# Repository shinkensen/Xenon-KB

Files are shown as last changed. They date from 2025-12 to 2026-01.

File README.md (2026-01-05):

# Xenon-KB

The Xenon KB is an 85%, fully rgb backlit (96 zone), fully wireless keyboard powered by an esp32 chip with a unique key design. 

<br/>
<br/>
More specifications:
<br/>
- CPG151101D01 Switches (From HanElectricty) https://www.lcsc.com/product-detail/C49234238.html
<br/>
- Backlit by an array of SK6812MINI-E's
<br/>
- 5000mah LiPo 1s 3.7v battery
<br/>
- Fully Custom Keycaps & Case
  <br/>
- Wireless with BLE from the onboard ESP-32
  <br/> 
- Rotary Encoder
<br/>
BOM:
https://docs.google.com/spreadsheets/d/1MoRKEyVhLm31BRy2YZbWCOqMzg5SxBg5gL_tJ-3HmaI/edit?usp=sharing
<br/>




<br/>
BOM for parts
https://drive.google.com/file/d/10kQmmBENU_pZNQ-ZYw2EzStenI3IcliA/view?usp=drive_link
<br/>

<br/>

Google Drive Folder: https://drive.google.com/drive/folders/1_GYV8TD-opU9jGdwIyMG7L0oK-KXUA7e?usp=sharing

<br/>
<br/>
Why I built this: Wanted a fully backlit keyboard for coding in the night. Also wanted a mechanical keyboard.
<br/>
<br/>

Images:



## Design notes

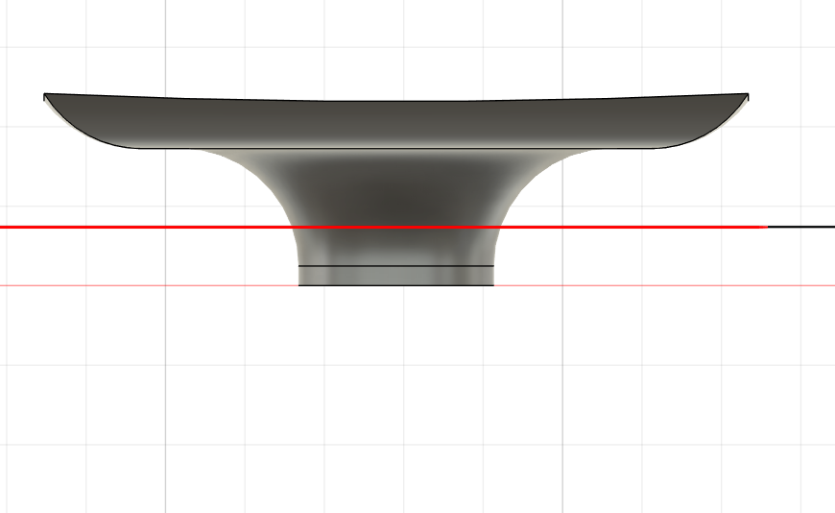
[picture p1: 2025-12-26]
CAD/Keycap.png

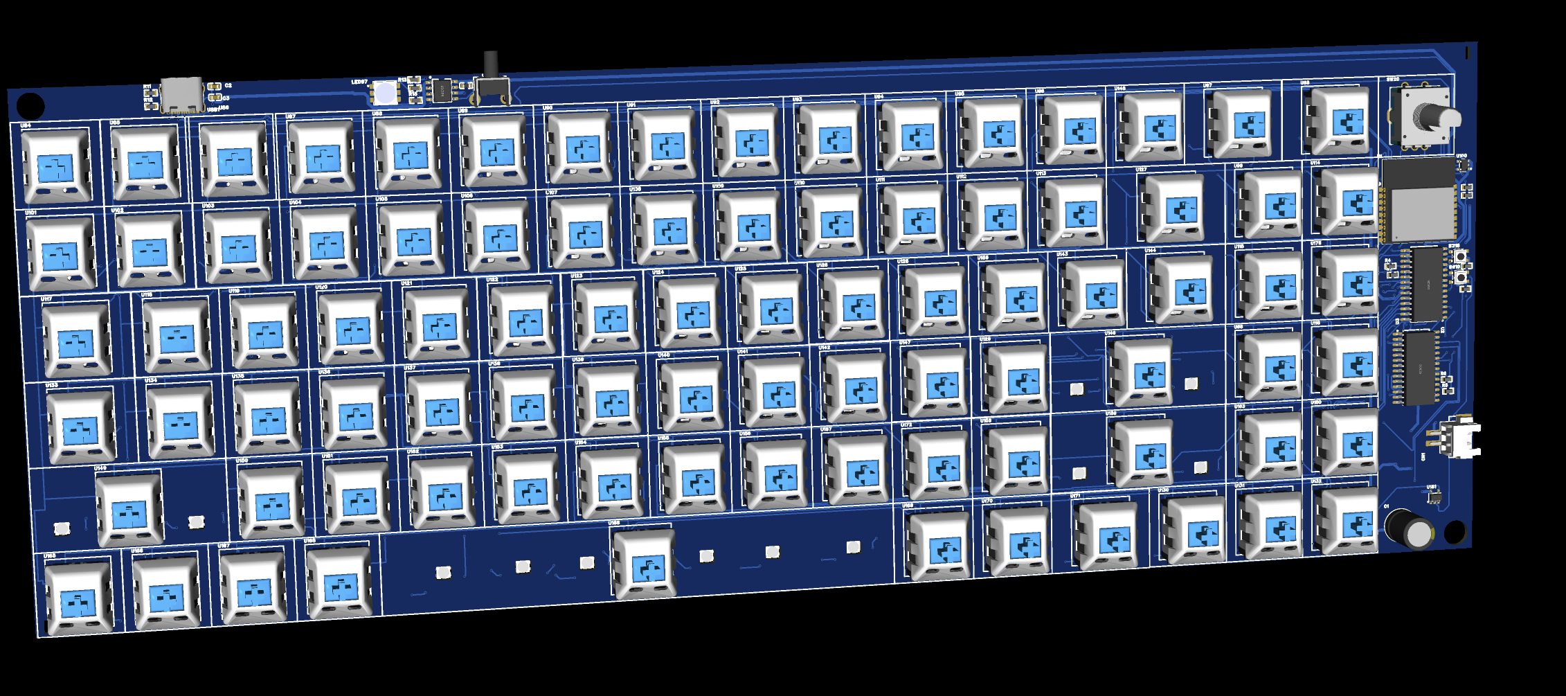
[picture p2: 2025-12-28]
pcb/PCB (Image 2).png

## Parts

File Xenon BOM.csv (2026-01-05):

Name | Cost | With Tax | Links | Links (Additional) | Column 6 | Column 1 | Column 2 | Column 3 | Column 4 | Column 5 | Column 7 | Column 8 | Column 9 | Column 10 | Column 11 | Column 12 | Column 13 | Column 14 | Column 15 | Column 16 | Column 17 | Column 18 | Column 19 | Column 20 | Column 21 | Column 22 | Column 23 | Column 25 | Column 27
PCB | $ 37.50 |  | https://drive.google.com/file/d/1959B7aU0yXcRoiEhPKL7f8_TZMNGbxId/view |  |  | LCSC# | Mfr. | Mrf# | Description | Package | Value | Customer Part Number | Quantity | Target Price(USD) | Target Lead Time(Business Days) | Mrf# | Mfr. | Order Qty. | Unit Price(USD) | Ext.Price(USD) | LCSC# | Package | Min | Mult | SPQ | Availability | Stock Status | Description | Product Link
Parts | $ 43.19 |  | https://drive.google.com/file/d/1eT5wwbHMu8irWbdyzTQDoIp_ezeuC_NU/view | https://drive.google.com/file/d/10kQmmBENU_pZNQ-ZYw2EzStenI3IcliA/view?usp=drive_link | <- BOM for parts -> | C49234238 | HanElectricity(瀚源) | CPG151101D01 | Switches | SW-TH_CPG151101D9X |  | - | 88 |  |  | CPG151101D01 | HanElectricity | 90 | 0.0809 | 7.28 | C49234238 | Through Hole | 5 | 5 | 500 | 4065 | In Stock | 60gf Black Switch Through Hole Pushbutton Switches RoHS | https://www.lcsc.com/product-detail/C49234238.html
battery | $14.24 |  | https://www.amazon.com/gp/product/B0D7LVP6RD/ref=ox_sc_act_title_1?smid=A1NOQTMMT39TJ0 |  |  | C2907044 | FOJAN(富捷) | FRC0603F5101TS | Ressistor | R0603 |  | - | 2 |  |  | FRC0603F5101TS | FOJAN | 100 | 0.0009 | 0.09 | C2907044 | 603 | 100 | 100 | 5000 | 4839000 | In Stock | 5.1kΩ ±1% 100mW 0603 Thick Film Resistor | https://www.lcsc.com/product-detail/C2907044.html
Case and Keycaps (Shipping) | $ 6.38 |  | https://drive.google.com/file/d/1fY9vsn8Mw1SYbBaPE8fCq7_2en8WSZ7o/view |  |  | C | SHOU HAN(首韩) | TYPE-C 16PIN 2MD(073) | USB-C | USB-C-SMD_TYPE-C-6PIN-2MD-073 |  | - | 1 |  |  | TYPE-C 16PIN 2MD(073) | SHOU HAN | 20 | 0.0631 | 1.26 | C2765186 | SMD | 20 | 20 | 1000 | 366060 | In Stock | USB-C (USB TYPE-C) Receptacle Connector 16 Position Surface Mount, Right Angle | https://www.lcsc.com/product-detail/C2765186.html
 |  |  |  |  |  | C1591 | SAMSUNG(三星) | CL10B104KB8NNNC | Capacitor | C0603 |  | - | 2 |  |  | CL10B104KB8NNNC | Samsung Electro-Mechanics | 100 | 0.0026 | 0.26 | C1591 | 603 | 100 | 100 | 4000 | 22834100 | In Stock | 100nF ±10% 50V Ceramic Capacitor X7R 0603 | https://www.lcsc.com/product-detail/C1591.html
 |  |  |  |  |  | C784540 | TCWIN(天成) | TC5050RGBF08-3CJH-AF53A | Charging statusLEDs | LED-SMD_6P-L5.0-W5.0-TL_TC5050RGBF08 |  | - | 1 |  |  | TC5050RGBF08-3CJH-AF53A | TCWIN | 20 | 0.0190 | 0.38 | C784540 | SMD5050-6P | 20 | 20 | 1000 | 430820 | In Stock | 200mW SMD5050-6P LED Indication - Discrete RoHS | https://www.lcsc.com/product-detail/C784540.html
 |  |  |  |  |  | C21190 | UNI-ROYAL(厚声) | 0603WAF1001T5E | Ressistor | R0603 |  | - | 3 |  |  | 0603WAF1001T5E | UNI-ROYAL | 100 | 0.0012 | 0.12 | C21190 | 603 | 100 | 100 | 5000 | 33306700 | In Stock | 1kΩ ±1% 100mW 0603 Thick Film Resistor | https://www.lcsc.com/product-detail/C21190.html
 |  |  |  |  |  | C181692 | INJOINIC(英集芯) | IP5306 | Charging Module | ESOP-8_L4.9-W3.9-P1.27-LS6.0-BL-EP |  | - | 1 |  |  | IP5306 | INJOINIC | 5 | 0.2659 | 1.33 | C181692 | ESOP-8 | 5 | 5 | 4000 | 10230 | In Stock | Lithium Battery I2C 2.1A ESOP-8 Battery Management RoHS | https://www.lcsc.com/product-detail/C181692.html
 |  |  |  |  |  | C2839970 | YJYCOIN(益嘉源) | YL160808-1R0K | Inductor | L0603 |  | - | 1 |  |  | YL160808-1R0K | YJYCOIN | 50 | 0.0152 | 0.76 | C2839970 | 603 | 50 | 50 | 4000 | 109750 | In Stock | 25mA 1uH ±10% 600mΩ 0603 Fixed Inductors RoHS | https://www.lcsc.com/product-detail/C2839970.html
 |  |  |  |  |  | C49393702 | SAMZO(三佐) | M22K095111F5 | Wake-up button | SW-TH_4P-L7.5-W9.5 |  | - | 1 |  |  | M22K095111F5 | SAMZO | 5 | 0.2013 | 1.01 | C49393702 | Through Hole | 5 | 5 | 1000 | 985 | In Stock | 1.8N SPST-NO 12V Through Hole Pushbutton Switches RoHS | https://www.lcsc.com/product-detail/C49393702.html
 | $ 101.31 | $ 110.43 |  |  |  | C25804 | UNI-ROYAL(厚声) | 0603WAF1002T5E | Ressistor | R0603 |  | - | 6 |  |  | 0603WAF1002T5E | UNI-ROYAL | 100 | 0.0011 | 0.11 | C25804 | 603 | 100 | 100 | 5000 | 32974600 | In Stock | 10kΩ ±1% 100mW 0603 Thick Film Resistor | https://www.lcsc.com/product-detail/C25804.html
 |  |  |  |  |  | C43832 | Chengx(承兴) | KM108M016F16RR0VH2FP0 | Capacitor | CAP-TH_BD8.0-P3.50-D0.5-FD |  | - | 1 |  |  | KM108M016F16RR0VH2FP0 | Chengx | 10 | 0.0556 | 0.56 | C43832 | Through Hole,D8xL16mm | 10 | 10 | 500 | 82800 | In Stock | 1000uF 16V Aluminum Electrolytic Capacitors Through Hole,D8xL16mm 2000hrs@105℃ | https://www.lcsc.com/product-detail/C43832.html
 |  |  |  |  |  | C143790 | BOURNS | PEC11R-4215F-S0024 | Rotary Encoder | SW-TH_5P-L12.5-W13.4-P2.50-LS14.5 |  | - | 1 |  |  | PEC11R-4215F-S0024 | BOURNS | 1 | 2.4676 | 2.47 | C143790 | Through Hole | 1 | 1 | 75 | 829 | In Stock | Through Hole Encoders RoHS | https://www.lcsc.com/product-detail/C143790.html
 |  |  |  |  |  | C629440 | MICROCHIP(美国微芯) | MCP23017T-E/SO | GPIO Expander | SOIC-28_L17.9-W7.5-P1.27-LS10.3-BL |  | - | 2 |  |  | MCP23017T-E/SO | MICROCHIP | 2 | 1.9539 | 3.91 | C629440 | SOIC-28-300mil | 1 | 1 | 1600 | 636 | In Stock | 16 I2C SOIC-28-300mil I/O Expanders RoHS | https://www.lcsc.com/product-detail/C629440.html
 |  |  |  |  |  | C2934560 | ESPRESSIF(乐鑫) | ESP32-C3-WROOM-02-N4 | ESP-32 | BULETM-SMD_ESPRESSIF_ESP32-C3-WROOM-02-N4-4MB |  | - | 1 |  |  | ESP32-C3-WROOM-02-N4 | ESPRESSIF | 1 | 3.0674 | 3.07 | C2934560 | VFQFN-32-EP | 1 | 1 | 650 | 7314 | In Stock | 2.4GHz ESP32-C3 Chip On-board PCB Antenna -98dBm VFQFN-32-EP RF Transceiver Modules and Modems RoHS | https://www.lcsc.com/product-detail/C2934560.html
 |  |  |  |  |  | C52140417 | MDD(辰达半导体) | 74AHCT1G125GV | Logic level shifter | SOT-23-5_L3.0-W1.7-P0.95-LS2.8-BL |  | - | 1 |  |  | 74AHCT1G125GV | MDD(Microdiode Semiconductor) | 1 | 0.0741 | 0.07 | C52140417 | SOT-23-5L | 1 | 1 | 3000 | 2744 | In Stock | 1 40uA 4.5V~5.5V 1 1ns@4.5V SOT-23-5L Buffers, Drivers, Receivers, Transceivers RoHS | https://www.lcsc.com/product-detail/C52140417.html
 |  |  |  |  |  | C3029476 | XUNPU(讯普) | WAFER-XH2.54-2PWB | Batt connector | CONN-SMD_2P-P2.54-XH2.54-WT |  | - | 1 |  |  | WAFER-XH2.54-2PWB | XUNPU | 5 | 0.0707 | 0.35 | C3029476 | SMD,P=2.5mm,Surface Mount,Right Angle | 5 | 5 | 700 | 14525 | In Stock | Connector Header 2 position 2.5mm Pitch 3A Surface Mount, Right Angle -25℃~+85℃ | https://www.lcsc.com/product-detail/C3029476.html
 |  |  |  |  |  | C455261 | XUNPU(讯普) | TS-1077S-02026 | Button (EN and Boot) | SW-SMD_L3.1-W3.1-P2.20-LS4.0 |  | - | 2 |  |  | TS-1077S-02026 | XUNPU | 10 | 0.0453 | 0.45 | C455261 | SMD,3.1x3.1mm | 10 | 10 | 4000 | 22540 | In Stock | Tactile Switch SPST 2mm 3.1mm x 3.1mm Surface Mount | https://www.lcsc.com/product-detail/C455261.html
 |  |  |  |  |  | C23380830 | TECH PUBLIC(台舟) | AP2112K-3.3TRG1 | Voltage reg (LDO) | SOT-23-5_L2.9-W1.6-P0.95-LS2.8-BR |  | - | 1 |  |  | AP2112K-3.3TRG1 | TECH PUBLIC | 5 | 0.0922 | 0.46 | C23380830 | SOT-23-5 | 5 | 5 | 3000 | 31810 | In Stock | Positive Fixed 3.3V SOT-23-5 Voltage Regulators - Linear, Low Drop Out (LDO) Regulators RoHS | https://www.lcsc.com/product-detail/C23380830.html
 |  |  |  |  |  | C2984443 | Viking(光颉) | ARG03FTC4001N | Ressistor | R0603 |  | - | 2 |  |  | ARG03FTC4001N | Viking | 100 | 0.0077 | 0.77 | C2984443 | 603 | 100 | 100 | 5000 | 49100 | In Stock | 4kΩ ±1% 100mW 0603 Thin Film Resistor | https://www.lcsc.com/product-detail/C2984443.html
 |  |  |  |  |  | C7423120 | 欧思科光电 | SK6812MINI-KA | Backlight Leds | LED-SMD_L3.2-W2.8-LS5.9_SK6812MINI-E |  | - | 96 |  |  | SK6812MINI-KA | OPSCO Optoelectronics | 100 | 0.0293 | 2.93 | C7423120 | - | 10 | 10 | 1000 | 290 | In Stock | LED Addressable, Specialty RoHS | https://www.lcsc.com/product-detail/C7423120.html
 |  |  |  |  |  | C51953478 | CCX(晁禾) | 1N4148W | Diodes | SOD-123_L2.7-W1.7-LS3.8-RD |  | - | 88 |  |  | 1N4148W | Chao He | 90 | 0.0058 | 0.52 | C51953478 | SOD-123 | 10 | 10 | 3000 | 135960 | In Stock | 2A 4ns 100V 1 Independent 1.25V@150mA 150mA SOD-123 Single Diodes RoHS | https://www.lcsc.com/product-detail/C51953478.html

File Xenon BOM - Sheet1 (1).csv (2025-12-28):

Name | Cost | Info | Links | Column 5 | Column 6
PCB | $ 39.98 |  | https://drive.google.com/file/d/1959B7aU0yXcRoiEhPKL7f8_TZMNGbxId/view
Parts | $ 42.59 | 40.71 after $5 coupon | https://drive.google.com/file/d/1eT5wwbHMu8irWbdyzTQDoIp_ezeuC_NU/view
battery | $ 11.79 |  | https://drive.google.com/file/d/1dXzgJhcJpep-MnbiQsx2OHDlmJTpkkL0/view | https://www.aliexpress.us/item/3256808681500642.html?mp=1
Case and Keycaps (Shipping) | $ 7.07 |  | https://drive.google.com/file/d/1fY9vsn8Mw1SYbBaPE8fCq7_2en8WSZ7o/view
 |  |  | With coupon
 | $ 101.43 | $ 110.56 | $ 108.51

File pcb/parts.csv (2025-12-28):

PCB1_Xenon_KB |  |  |  |  |  |  |  |  |  | LCSC BOM Quotation
 |  |  |  |  |  |  |  |  |  | BOM Date Created：29/12/25 06:02:05 |  |  |  | BOM Export Date: 29/12/25 06:02:48 |  |  |  | The matching result is a real-time query result, availability and prices may fluctuate. Backorder items are estimated prices for your reference, please submit "Create Quote" to get the real price. All information is provided "as is" and is subject to change without notice. Any use made of the information provided is without recourse to LCSC and at the user's risk.
 |  |  |  |  |  |  |  |  |  | EST TOTAL :$30.67 |  |  |  | Website：https://www.lcsc.com/bom
Uploaded data |  |  |  |  |  |  |  |  |  | LCSC Matching Results
LCSC# | Mfr. | Mrf# | Description | Package | Value | Customer Part Number | Quantity | Target Price(USD) | Target Lead Time(Business Days) | Mrf# | Mfr. | Order Qty. | Unit Price(USD) | Ext.Price(USD) | LCSC# | Package | Min | Mult | SPQ | Availability | Stock Status | Customer Notes | Description | Matched status | Product Link
C49234238 | HanElectricity(瀚源) | CPG151101D01 |  | SW-TH_CPG151101D9X |  | - | 88 |  |  | CPG151101D01 | HanElectricity | 90 | 0.0769 | 6.92 | C49234238 | Through Hole | 5 | 5 | 500 | 4065 | In Stock |  | 60gf Black Switch Through Hole Pushbutton Switches RoHS | Exact Matches | https://www.lcsc.com/product-detail/C49234238.html
C2907044 | FOJAN(富捷) | FRC0603F5101TS |  | R0603 |  | - | 2 |  |  | FRC0603F5101TS | FOJAN | 100 | 0.0009 | 0.09 | C2907044 | 0603 | 100 | 100 | 5000 | 4839000 | In Stock |  | 5.1kΩ ±1% 100mW 0603 Thick Film Resistor | Exact Matches | https://www.lcsc.com/product-detail/C2907044.html
C | SHOU HAN(首韩) | TYPE-C 16PIN 2MD(073) |  | USB-C-SMD_TYPE-C-6PIN-2MD-073 |  | - | 1 |  |  | TYPE-C 16PIN 2MD(073) | SHOU HAN | 20 | 0.0600 | 1.20 | C2765186 | SMD | 20 | 20 | 1000 | 366060 | In Stock |  | USB-C (USB TYPE-C) Receptacle Connector 16 Position Surface Mount, Right Angle | Partial Matches | https://www.lcsc.com/product-detail/C2765186.html
C1591 | SAMSUNG(三星) | CL10B104KB8NNNC |  | C0603 |  | - | 2 |  |  | CL10B104KB8NNNC | Samsung Electro-Mechanics | 100 | 0.0026 | 0.26 | C1591 | 0603 | 100 | 100 | 4000 | 22834100 | In Stock |  | 100nF ±10% 50V Ceramic Capacitor X7R 0603 | Exact Matches | https://www.lcsc.com/product-detail/C1591.html
C784540 | TCWIN(天成) | TC5050RGBF08-3CJH-AF53A |  | LED-SMD_6P-L5.0-W5.0-TL_TC5050RGBF08 |  | - | 1 |  |  | TC5050RGBF08-3CJH-AF53A | TCWIN | 20 | 0.0190 | 0.38 | C784540 | SMD5050-6P | 20 | 20 | 1000 | 430820 | In Stock |  | 200mW SMD5050-6P LED Indication - Discrete RoHS | Exact Matches | https://www.lcsc.com/product-detail/C784540.html
C21190 | UNI-ROYAL(厚声) | 0603WAF1001T5E |  | R0603 |  | - | 3 |  |  | 0603WAF1001T5E | UNI-ROYAL | 100 | 0.0011 | 0.11 | C21190 | 0603 | 100 | 100 | 5000 | 33306700 | In Stock |  | 1kΩ ±1% 100mW 0603 Thick Film Resistor | Exact Matches | https://www.lcsc.com/product-detail/C21190.html
C181692 | INJOINIC(英集芯) | IP5306 |  | ESOP-8_L4.9-W3.9-P1.27-LS6.0-BL-EP |  | - | 1 |  |  | IP5306 | INJOINIC | 5 | 0.2693 | 1.35 | C181692 | ESOP-8 | 5 | 5 | 4000 | 10230 | In Stock |  | Lithium Battery I2C 2.1A ESOP-8 Battery Management RoHS | Exact Matches | https://www.lcsc.com/product-detail/C181692.html
C2839970 | YJYCOIN(益嘉源) | YL160808-1R0K |  | L0603 |  | - | 1 |  |  | YL160808-1R0K | YJYCOIN | 50 | 0.0152 | 0.76 | C2839970 | 0603 | 50 | 50 | 4000 | 109750 | In Stock |  | 25mA 1uH ±10% 600mΩ 0603 Fixed Inductors RoHS | Exact Matches | https://www.lcsc.com/product-detail/C2839970.html
C49393702 | SAMZO(三佐) | M22K095111F5 |  | SW-TH_4P-L7.5-W9.5 |  | - | 1 |  |  | M22K095111F5 | SAMZO | 5 | 0.2013 | 1.01 | C49393702 | Through Hole | 5 | 5 | 1000 | 985 | In Stock |  | 1.8N SPST-NO 12V Through Hole Pushbutton Switches RoHS | Exact Matches | https://www.lcsc.com/product-detail/C49393702.html
C25804 | UNI-ROYAL(厚声) | 0603WAF1002T5E |  | R0603 |  | - | 6 |  |  | 0603WAF1002T5E | UNI-ROYAL | 100 | 0.0010 | 0.10 | C25804 | 0603 | 100 | 100 | 5000 | 32974600 | In Stock |  | 10kΩ ±1% 100mW 0603 Thick Film Resistor | Exact Matches | https://www.lcsc.com/product-detail/C25804.html
C43832 | Chengx(承兴) | KM108M016F16RR0VH2FP0 |  | CAP-TH_BD8.0-P3.50-D0.5-FD |  | - | 1 |  |  | KM108M016F16RR0VH2FP0 | Chengx | 10 | 0.0556 | 0.56 | C43832 | Through Hole,D8xL16mm | 10 | 10 | 500 | 82800 | In Stock |  | 1000uF 16V Aluminum Electrolytic Capacitors Through Hole,D8xL16mm 2000hrs@105℃ | Exact Matches | https://www.lcsc.com/product-detail/C43832.html
C143790 | BOURNS | PEC11R-4215F-S0024 |  | SW-TH_5P-L12.5-W13.4-P2.50-LS14.5 |  | - | 1 |  |  | PEC11R-4215F-S0024 | BOURNS | 1 | 2.4676 | 2.47 | C143790 | Through Hole | 1 | 1 | 75 | 829 | In Stock |  | Through Hole Encoders RoHS | Exact Matches | https://www.lcsc.com/product-detail/C143790.html
C629440 | MICROCHIP(美国微芯) | MCP23017T-E/SO |  | SOIC-28_L17.9-W7.5-P1.27-LS10.3-BL |  | - | 2 |  |  | MCP23017T-E/SO | MICROCHIP | 2 | 1.9539 | 3.91 | C629440 | SOIC-28-300mil | 1 | 1 | 1600 | 636 | In Stock |  | 16 I2C SOIC-28-300mil I/O Expanders RoHS | Exact Matches | https://www.lcsc.com/product-detail/C629440.html
C2934560 | ESPRESSIF(乐鑫) | ESP32-C3-WROOM-02-N4 |  | BULETM-SMD_ESPRESSIF_ESP32-C3-WROOM-02-N4-4MB |  | - | 2 |  |  | ESP32-C3-WROOM-02-N4 | ESPRESSIF | 2 | 3.0674 | 6.13 | C2934560 | VFQFN-32-EP | 1 | 1 | 650 | 7314 | In Stock |  | 2.4GHz ESP32-C3 Chip On-board PCB Antenna -98dBm VFQFN-32-EP RF Transceiver Modules and Modems RoHS | Exact Matches | https://www.lcsc.com/product-detail/C2934560.html
C52140417 | MDD(辰达半导体) | 74AHCT1G125GV |  | SOT-23-5_L3.0-W1.7-P0.95-LS2.8-BL |  | - | 1 |  |  | 74AHCT1G125GV | MDD(Microdiode Semiconductor) | 1 | 0.0741 | 0.07 | C52140417 | SOT-23-5L | 1 | 1 | 3000 | 2744 | In Stock |  | 1 40uA 4.5V~5.5V 1 1ns@4.5V SOT-23-5L Buffers, Drivers, Receivers, Transceivers RoHS | Exact Matches | https://www.lcsc.com/product-detail/C52140417.html
C3029476 | XUNPU(讯普) | WAFER-XH2.54-2PWB |  | CONN-SMD_2P-P2.54-XH2.54-WT |  | - | 1 |  |  | WAFER-XH2.54-2PWB | XUNPU | 5 | 0.0672 | 0.34 | C3029476 | SMD,P=2.5mm,Surface Mount,Right Angle | 5 | 5 | 700 | 14525 | In Stock |  | Connector Header 2 position 2.5mm Pitch 3A Surface Mount, Right Angle -25℃~+85℃ | Exact Matches | https://www.lcsc.com/product-detail/C3029476.html
C455261 | XUNPU(讯普) | TS-1077S-02026 |  | SW-SMD_L3.1-W3.1-P2.20-LS4.0 |  | - | 2 |  |  | TS-1077S-02026 | XUNPU | 10 | 0.0431 | 0.43 | C455261 | SMD,3.1x3.1mm | 10 | 10 | 4000 | 22540 | In Stock |  | Tactile Switch SPST 2mm 3.1mm x 3.1mm Surface Mount | Exact Matches | https://www.lcsc.com/product-detail/C455261.html
C23380830 | TECH PUBLIC(台舟) | AP2112K-3.3TRG1 |  | SOT-23-5_L2.9-W1.6-P0.95-LS2.8-BR |  | - | 1 |  |  | AP2112K-3.3TRG1 | TECH PUBLIC | 5 | 0.0922 | 0.46 | C23380830 | SOT-23-5 | 5 | 5 | 3000 | 31810 | In Stock |  | Positive Fixed 3.3V SOT-23-5 Voltage Regulators - Linear, Low Drop Out (LDO) Regulators RoHS | Exact Matches | https://www.lcsc.com/product-detail/C23380830.html
C2984443 | Viking(光颉) | ARG03FTC4001N |  | R0603 |  | - | 2 |  |  | ARG03FTC4001N | Viking | 100 | 0.0076 | 0.76 | C2984443 | 0603 | 100 | 100 | 5000 | 49100 | In Stock |  | 4kΩ ±1% 100mW 0603 Thin Film Resistor | Exact Matches | https://www.lcsc.com/product-detail/C2984443.html
C7423120 | 欧思科光电 | SK6812MINI-KA |  | LED-SMD_L3.2-W2.8-LS5.9_SK6812MINI-E |  | - | 96 |  |  | SK6812MINI-KA | OPSCO Optoelectronics | 100 | 0.0284 | 2.84 | C7423120 | - | 10 | 10 | 1000 | 290 | In Stock |  | LED Addressable, Specialty RoHS | Exact Matches | https://www.lcsc.com/product-detail/C7423120.html
C51953478 | CCX(晁禾) | 1N4148W |  | SOD-123_L2.7-W1.7-LS3.8-RD |  | - | 88 |  |  | 1N4148W | Chao He | 90 | 0.0058 | 0.52 | C51953478 | SOD-123 | 10 | 10 | 3000 | 135960 | In Stock |  | 2A 4ns 100V 1 Independent 1.25V@150mA 150mA SOD-123 Single Diodes RoHS | Exact Matches | https://www.lcsc.com/product-detail/C51953478.html

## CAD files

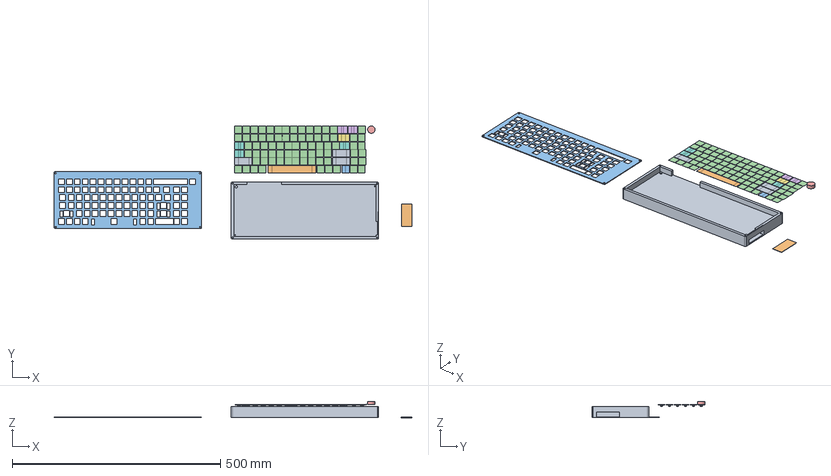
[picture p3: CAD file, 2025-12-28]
CAD/KB.step
859.3 x 271.7 x 39.1 mm

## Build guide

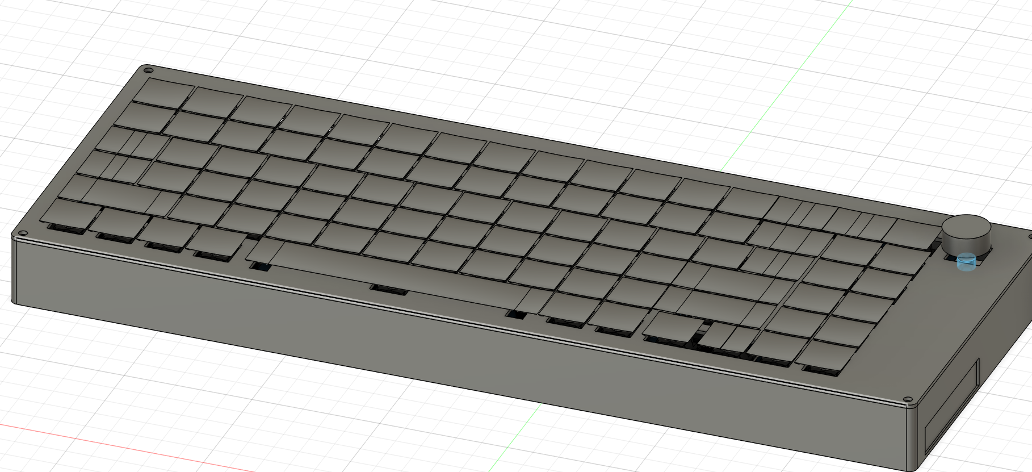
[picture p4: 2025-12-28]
CAD/Assembled.png

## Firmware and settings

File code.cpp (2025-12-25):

// ESP32 16x6 keyboard matrix + SK6812mini-e backlight
// Columns: MCP23017 @ 0x21 (A2=0, A1=0, A0=1) — all 16 pins used
// Rows:    MCP23017 @ 0x20 (A2=0, A1=0, A0=0) — GPA0..GPA5 used
// LEDs:    SK6812mini-e chain on GPIO 3 (~96 LEDs)

#include <Wire.h>
#include <Adafruit_MCP23X17.h>
#include <Adafruit_NeoPixel.h>

constexpr uint8_t SDA_PIN = 0;    // IO0 (strapping; keep pulled up at boot)
constexpr uint8_t SCL_PIN = 1;    // IO1
constexpr uint32_t I2C_FREQ = 400000;

constexpr uint8_t COL_ADDR = 0x21;  // columns expander address
constexpr uint8_t ROW_ADDR = 0x20;  // rows expander address

constexpr uint8_t ROW_COUNT = 6;
constexpr uint8_t COL_COUNT = 16;

constexpr uint8_t LED_PIN = 3;       // GPIO3
constexpr uint16_t LED_COUNT = 96;
constexpr uint8_t LED_BRIGHTNESS = 32;

Adafruit_MCP23X17 mcpCols;
Adafruit_MCP23X17 mcpRows;
Adafruit_NeoPixel pixels(LED_COUNT, LED_PIN, NEO_GRBW + NEO_KHZ800);

bool keyState[ROW_COUNT][COL_COUNT];

void setup() {
  Serial.begin(115200);
  Wire.begin(SDA_PIN, SCL_PIN, I2C_FREQ);

  if (!mcpCols.begin_I2C(COL_ADDR)) {
    Serial.println("Cols MCP init failed");
    while (true) {}
  }
  if (!mcpRows.begin_I2C(ROW_ADDR)) {
    Serial.println("Rows MCP init failed");
    while (true) {}
  }

  // Columns as outputs, idle HIGH
  for (uint8_t c = 0; c < COL_COUNT; c++) {
    mcpCols.pinMode(c, OUTPUT);
    mcpCols.digitalWrite(c, HIGH);
  }

  // Rows as inputs with pull-ups (GPA0..GPA5)
  for (uint8_t r = 0; r < ROW_COUNT; r++) {
    mcpRows.pinMode(r, INPUT_PULLUP);
  }

  pixels.begin();
  pixels.setBrightness(LED_BRIGHTNESS);
  pixels.clear();
  pixels.show();
}

void scanMatrix() {
  // Clear current state
  for (uint8_t r = 0; r < ROW_COUNT; r++) {
    for (uint8_t c = 0; c < COL_COUNT; c++) {
      keyState[r][c] = false;
    }
  }

  for (uint8_t c = 0; c < COL_COUNT; c++) {
    // Drive one column low, others high
    for (uint8_t cc = 0; cc < COL_COUNT; cc++) {
      mcpCols.digitalWrite(cc, cc == c ? LOW : HIGH);
    }

    delayMicroseconds(5); // allow signals to settle

    for (uint8_t r = 0; r < ROW_COUNT; r++) {
      bool pressed = (mcpRows.digitalRead(r) == LOW);
      keyState[r][c] = pressed;
    }
  }

  // Return columns to idle high
  for (uint8_t c = 0; c < COL_COUNT; c++) {
    mcpCols.digitalWrite(c, HIGH);
  }
}

void showDemoLeds() {
  // Simple moving white pixel to verify LED chain
  static uint16_t pos = 0;
  pixels.clear();
  pixels.setPixelColor(pos % LED_COUNT, pixels.Color(0, 0, 0, 255));
  pixels.show();
  pos++;
}

void loop() {
  scanMatrix();

  // Example: print pressed keys
  for (uint8_t r = 0; r < ROW_COUNT; r++) {
    for (uint8_t c = 0; c < COL_COUNT; c++) {
      if (keyState[r][c]) {
        Serial.print("Key r");
        Serial.print(r);
        Serial.print(" c");
        Serial.print(c);
        Serial.println(" pressed");
      }
    }
  }

  showDemoLeds();
  delay(5); // tune scan cadence
}

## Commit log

2025-12-25 Rename Screenshot 2025-12-24 214840.png to pcb/PCB.png
2025-12-25 Rename ProPrj_Xenon KB_2025-12-24.epro to pcb/ProPrj_Xenon KB_2025-12-24.epro
2025-12-25 Add ESP32 keyboard matrix and LED control
    Initial implementation of an ESP32 keyboard matrix with LED backlighting.
2025-12-28 Rename Screenshot 2025-12-28 131333.png to Assembled.png
2025-12-28 Rename Screenshot 2025-12-28 145623.png to pcb.png
2025-12-28 Rename pcb.png to PCB (Image 2).png
2025-12-28 Enhance README with specifications and links
    Added detailed specifications, BOM link, and images.
2025-12-28 Update and rename Xenon BOM - Sheet1 (1).csv to Xenon BOM.csv
    [Xenon BOM.csv]
2025-12-28 Update Xenon BOM.csv
    [Xenon BOM.csv]
2026-01-03 Update and rename Xenon BOM - Sheet1 (2).csv to Xenon BOM.csv
    [Xenon BOM.csv]
2026-01-03 Update and rename Xenon BOM - Sheet1 (3).csv to Xenon BOM.csv
    [Xenon BOM.csv]
2026-01-03 Revise Xenon BOM with new items and pricing
    Updated the Xenon BOM CSV file to include new items and adjusted pricing.
    [Xenon BOM.csv]
